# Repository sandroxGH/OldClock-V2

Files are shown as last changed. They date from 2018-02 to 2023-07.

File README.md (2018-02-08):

Old Clock V2.0
===================== 
Controller board for Odl train station clock 

Project preview
=====================
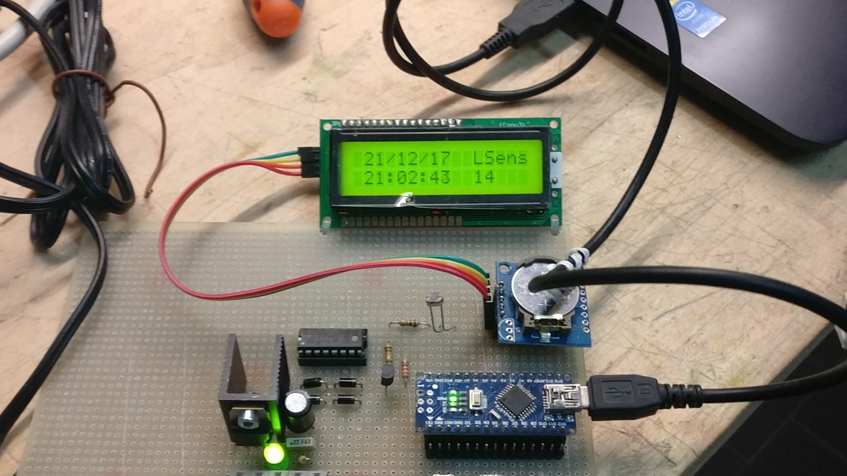
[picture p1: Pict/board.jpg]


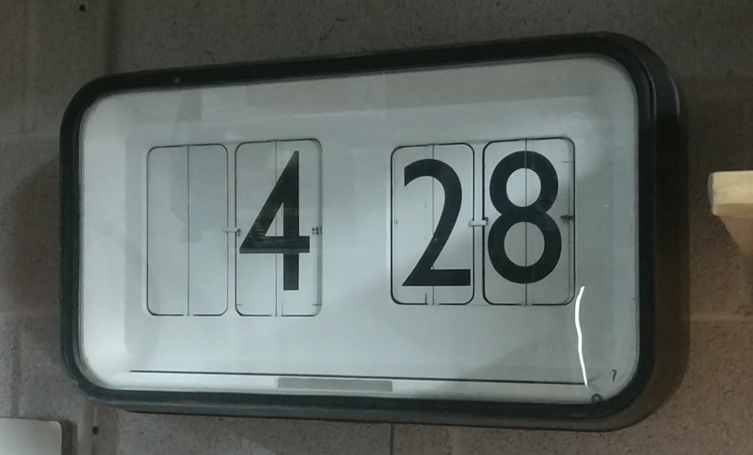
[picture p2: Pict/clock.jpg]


License and copyright
=====================

Copyright 2017-2018 sandroxGH infomsystemsrl@gmail.com

Licensed under the Apache License, Version 2.0 (the "License"); you may not use this file except in compliance with the License. You may obtain a copy of the License at http://www.apache.org/licenses/LICENSE-2.0

Unless required by applicable law or agreed to in writing, software distributed under the License is distributed on an "AS IS" BASIS, WITHOUT WARRANTIES OR CONDITIONS OF ANY KIND, either express or implied. See the License for the specific language governing permissions and limitations under the License.

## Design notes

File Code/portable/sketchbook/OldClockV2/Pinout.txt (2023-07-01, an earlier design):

1	D1/TX	SerialCon 
2	D0/RX	SerialCon
3	RESET
4	GND
5	D2*		Edit Button
6	D3		Up Button
7	D4		Down Button
8	D5*		Sensor for 0 meccanical detect
9	D6* 		Motor Direction 
10	D7		Motor Enable 
11	D8		Periphral Power 
12	D9* 		Green Led For Debug 
13	D10*		
14	D11* 		Led light 
15	D12  	
16	D13		Red Led program State 
17	3V3		
18	AREF
19	A7		
20	A6		
21	A5		
22	A4		
23	A3		
24	A2		
25	A1		Supply voltage control 
26	A0		Light Dependent Resistor
27	+5V
28	RESET
29	GND
30	VIN

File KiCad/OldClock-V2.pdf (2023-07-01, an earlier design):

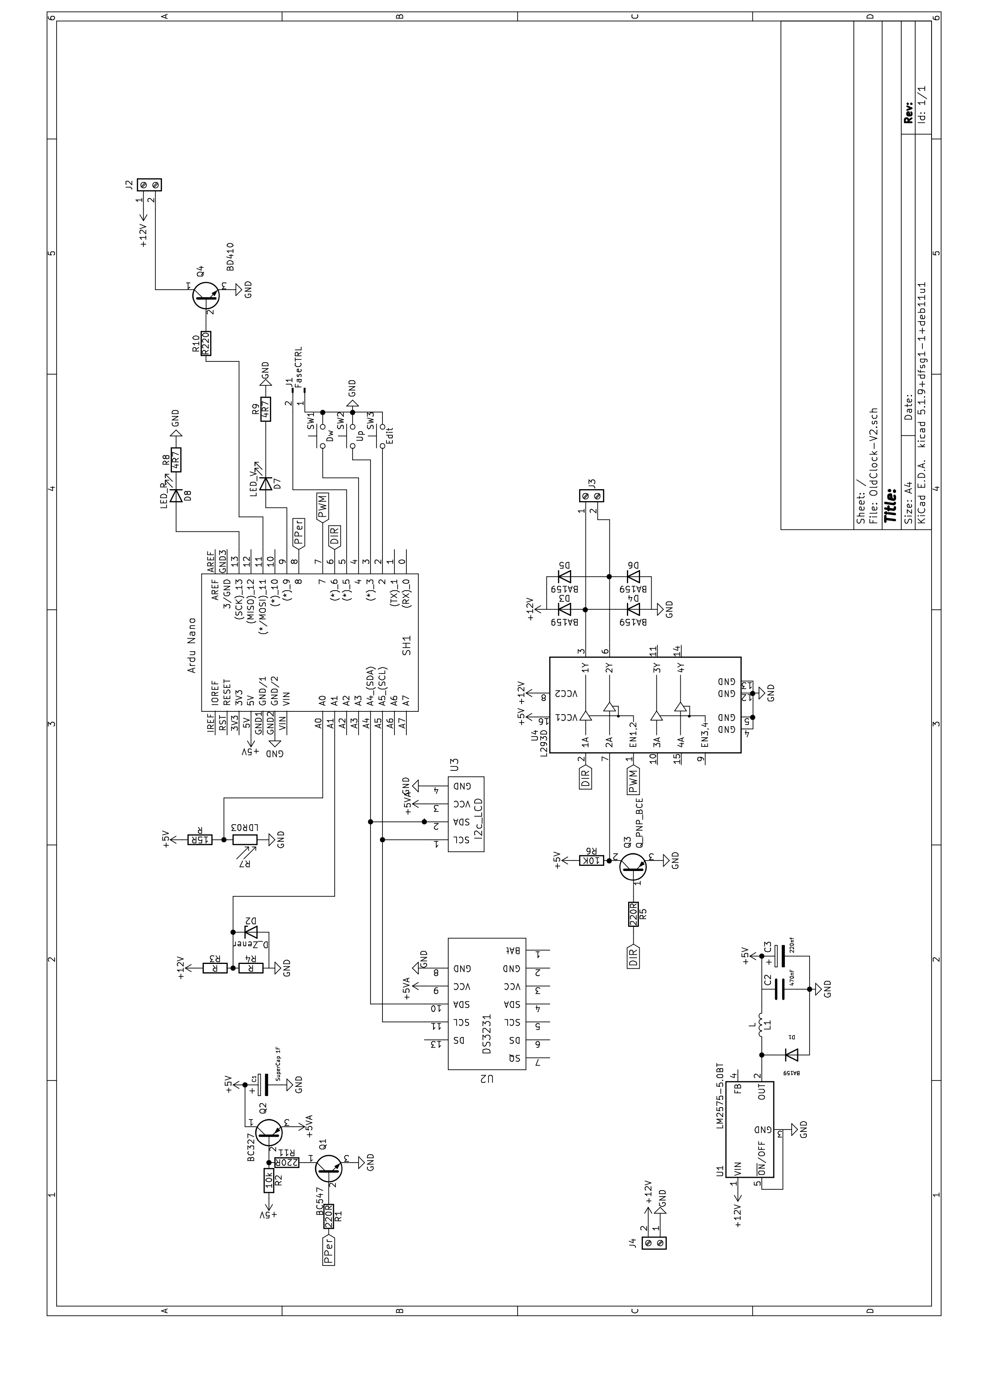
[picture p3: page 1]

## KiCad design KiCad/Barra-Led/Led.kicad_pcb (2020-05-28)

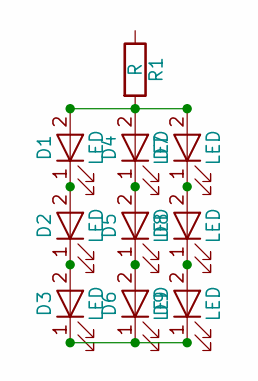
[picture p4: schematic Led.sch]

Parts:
D1, D2, D3, D4, D5, D6, D7, D8, D9: LED; 3528
R1: R; R_1210_HandSoldering

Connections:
unnamed: D1.1 (K), D2.2 (A)
unnamed: D1.2 (A), D4.2 (A), D7.2 (A), R1.2
unnamed: D2.1 (K), D3.2 (A)
unnamed: D3.1 (K), D6.1 (K), D9.1 (K)
unnamed: D4.1 (K), D5.2 (A)
unnamed: D5.1 (K), D6.2 (A)
unnamed: D7.1 (K), D8.2 (A)
unnamed: D8.1 (K), D9.2 (A)

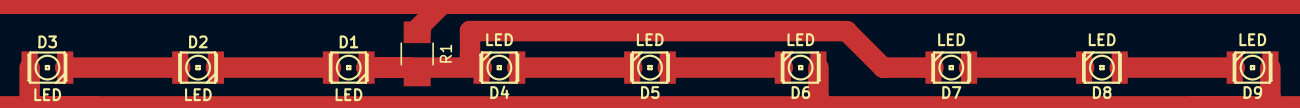
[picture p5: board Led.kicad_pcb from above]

Board: 2 copper layers, 10 parts (0 on the bottom side), 8 nets.

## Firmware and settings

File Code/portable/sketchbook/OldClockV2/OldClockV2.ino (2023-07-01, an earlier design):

/*
  Old clock for rail station V2.1
   This project is to control a flip clock using arduino nano with DS3231 RTC board,
   also a twilight control for night light.
   Can adjust: the date and time, motor speed for pallet revolution, twilight
   threshold, voltage supply allarm and event/alarm log history.
*/

#include <Wire.h>
#include <LCD.h>
#include <LiquidCrystal_I2C.h>
#include <EEPROM.h>
#include <avr/wdt.h>

//---------Alarm table-----------------
#define EVENT			'E'
#define ALARM			'A'
#define MESSAGE			'M'
#define START_UP		1
#define CHANGE_DATE		2
#define DATA_FAULT		3
#define MCL_WAITING		4
#define MCL_ADVANCE		5
#define MCL_DELAY		6
#define LCD_BUS_FAULT	7
#define RTC_BUSS_FAULT	8
#define EPR_BUSS_FAULT	9
#define RTC_NOT_RUN		10
#define SAVE_SHUTDOWN	11
#define SUMMER_TIME		12
#define STANDARD_TIME	13

//-------Alarm Led Blink Pattern-------
#define Pattern_No_All	2500
#define Pattern_All1    1000
#define Pattern_All2    500
#define Pattern_All3    200

//-----------Timer Setting-------------
#define EepromWipe		0 		// init procedure for new eeprom
#define EepromRead		0   	// all the eprom data is print on serial port in startup
#define SystemLog		1		// Enable of System Log on external eprom
#define FDebug			0		// Enable Fast Debug
#define SDebug			0		// Eneble Time Debug
#define TDebug			1000	// Time of debug 
#define TLcd			1000	// Time Lcd Refresh 
#define TTwl			2000	// Time for LDR value calculation
//#define TMotMan		61000	// Time 
#define TPatAll			30000	// Time of led alarm indication 
#define TExitMenu		30000	// Time for auto-exit menu 
#define TI2cTest		30000	// Time for bus test 
#define TSvTShDw		500		// Time to Save and Shutdown , power off the PerPwr enable

#define SelPatt			50		// Selection minimal time 
#define EntPatt			1500	// Enter
#define TPulButt		100		// Time for auto toogles button  

#define MenuPage		7		// Number of page in Menu 
#define SampleN			10		// Sample number for LDR Value 
#define TwlRDelta		30		// Delta between the Min and Max threshold in Twilight parameter 


#define UpLimMS			250		// Motor Speed limit
#define DwLimMS			12
#define UpLimTwlOn		250		// Twilight Sensor limit ON
#define DwLimTwlOn		10
#define	UpLimTwlOff		250		// Twilight Sensor limit OFF
#define DwLimTwlOff		10
#define UpLimVSens		140   // Limit for auto power off
#define DwLimVSens		50
#define HiEpromLim		4020	// Message limit for system log %10
#define LowEpromLim		0
#define EepromPageSize	32
#define SerAllMes		2



//---------LCD I2C Addres and pinout---
#define EEPROM_ADDR		0x57 ///0x50  simulator
#define LCD_I2C_ADDR	0x27 //0x20  simulator
#define DS3231_ADDR		0x68
//#define DS1307_ADDR	0x68
#define BACKLIGHT_PIN	3
#define En_pin			2
#define Rw_pin			1
#define Rs_pin			0
#define D4_pin			4
#define D5_pin			5
#define D6_pin			6
#define D7_pin			7


//----------Arduino PinOut-------------
#define EdButt		2
#define UpButt		3
#define DwButt		4  //5 simulator
#define FaseCTRL	5  //4 simulator
#define LDR			A0
#define VSens		A1  //Vin-Vout ratio 0.33
#define Light		11
#define LedV		9
#define LedR		13
#define MotDir		6
#define MotEn		7
#define PerPwr		8


//-----Arduino EEPROM data storage-----
#define M_MotSpeed		1
#define M_TwlR_On	  	2						//Twilight relays threshold On
#define M_TwlR_Off		3						//Twilight relays threshold Off
#define M_HMec			4
#define M_MMec			5
#define M_MDir			6
#define M_EpromAdd		7
#define M_EpromAdd1		8
#define M_VSensLim		9     // 12V Sensor limit under this limit save the parameter and disable motor movement 
#define M_SolarTime		10


unsigned long TimeLcd = 0;  		//Update LCD Time
unsigned long TimeDeb = 0;  		//Debug Time
unsigned long TimeTwl = 0;		//
unsigned long TimeMotMan = 0;		// Time to update the Mechanical time
unsigned long TimeMotEn = 0;
unsigned long TimeBlink = 0;
unsigned long TimeEdButt = 0;
unsigned long TimeUpButt	= 0;
unsigned long TimeDwButt = 0;
unsigned long TimePatt	= 0;
unsigned long TimeMenu 	= 0;
unsigned long TimeI2cTest = 0;
unsigned long TimeSvTShDw = 0;
unsigned long TimePulseUp	= 0;
unsigned long TimePulseDw  = 0;
unsigned long TMotMgmt =0;
unsigned long TMotEn =0;

byte DataTime[7];
byte SetDataTime[7];
byte AllBuff[10];
char buffer[30];
byte SerAll[3];
byte EpromPageOffset = 0;
byte NotAligLengt  = 0;

int EpromAdd;
unsigned int Pattern = 0;
int SetData, SetDataOld;
int HMec, MMec ;
int MotEnable;
int TwlR_On, TwlR_Off, TwlAve, TwlVal;
int VSensVal;
int VSensValOld;
int VSensLim;
int j,i;
int SumMinMec = 0;
int SumMinRtc = 0;
int MinOld =0;

char EditState = 0;
char Menu = 0;
char MenuOld = 0;
char Cursor, OldCursor;
char Sample;
char UpButtState, DwButtState;
char SerCount;
char SolarTime;
const char* DW[] = {"Lun", "Mar", "Mer","Gio", "Ven", "Sab", "Dom"}; //Day of week
const char* Adj[] = {"Leg","Sol","xxx"}; //Summer Standard time auto Adjust




byte Char10[8] = {
  B00010, B00100, B01000, B10000, B01011, B11011, B01011, B01011
};
byte CharV[8] = {
  B10001, B10001, B01010, B01010, B00100, B00001, B00010, B00100
};

bool AllReady  = 0;
bool MClAdAll  = 0;
bool MClDlAll  = 0;
bool MClWaAll	= 0;
bool LcdAll    = 0;
bool RtcAll    = 0;
bool EpromAll  = 0;
bool PattAllOn = 0;
bool MoveMot   = 0;
bool EditMode  = 0;
bool InitEdit  = 0;
bool SvTShDw  = 0;
bool PulseMem = 0;
bool LcdClear =0;

LiquidCrystal_I2C lcd(LCD_I2C_ADDR, En_pin, Rw_pin, Rs_pin, D4_pin, D5_pin, D6_pin, D7_pin);

void(* resetFunc) (void) = 0;   //Reset SW

void setup() {
  pinMode(EdButt, INPUT_PULLUP);
  pinMode(UpButt, INPUT_PULLUP);
  pinMode(DwButt, INPUT_PULLUP);
  pinMode(FaseCTRL, INPUT_PULLUP);
  pinMode(Light, OUTPUT);
  pinMode(LedR, OUTPUT);
  pinMode(LedV, OUTPUT);
  pinMode(MotDir, OUTPUT);
  pinMode(MotEn, OUTPUT);
  pinMode(PerPwr, OUTPUT);
  analogReference(DEFAULT);
  digitalWrite(PerPwr, HIGH);      //Turne On The Periferical Power
  delay(500);
  Wire.begin();
  lcd.begin(16, 2);
  lcd.createChar(6, CharV);
  lcd.createChar(7, Char10);
  Serial.begin(115200);
  Serial.println("OdlClockV2.2");
  lcd.setBacklightPin(BACKLIGHT_PIN, POSITIVE);
  lcd.setBacklight(HIGH);
  lcd.setCursor(4 , 0);
  lcd.print("Msystem");
  lcd.setCursor(1, 1);
  lcd.print("Old Clock V2.2");
  delay(1500);
  lcd.clear();
  lcd.setBacklight(LOW);
  MotEnable = EEPROM.read(M_MotSpeed);
  TwlR_On = EEPROM.read(M_TwlR_On);
  TwlR_Off = EEPROM.read(M_TwlR_Off);
  HMec = EEPROM.read(M_HMec);
  MMec = EEPROM.read(M_MMec);
  EpromAdd = EEPROM.read(M_EpromAdd1);
  EpromAdd = (EpromAdd << 8) + EEPROM.read(M_EpromAdd);
  EpromAdd += 10;
  digitalWrite(MotDir , EEPROM.read(M_MDir));
  VSensLim = EEPROM.read(M_VSensLim);
  SolarTime= EEPROM.read(M_SolarTime);

  // EpromAdd = 0;
  if (EpromAdd < LowEpromLim) EpromAdd = LowEpromLim;
  if (EepromWipe) {
    Serial.println("Erasing EEPROM");
    lcd.setCursor(1 , 0);
    lcd.print("Erasing EEPROM");
    for (j = 0; j < 10; j++) AllBuff[j] = 0;
    AllBuff[7] = '#';
    for (j = LowEpromLim; j <= HiEpromLim; j += 10)  EEpromWriteBuff(EEPROM_ADDR , j, &AllBuff[0], 10);
    EEPROM.write(M_EpromAdd, 0);
    EEPROM.write(M_EpromAdd1, 0);
    EpromAdd = LowEpromLim;
  }
  if (EepromRead) {
    Serial.println("EEPROM read Mesage");
    for (j = LowEpromLim; j <= HiEpromLim; j += 10) {
      EEpromReadBuff(EEPROM_ADDR , j, &AllBuff[0], 10);
      sprintf(buffer, "%02d;%02d/%02d/%02d;%02d:%02d:%02d;%c;%02d;%02d", ((j - LowEpromLim) / 10), AllBuff[2], AllBuff[1], AllBuff[0], AllBuff[4], AllBuff[5], AllBuff[6], AllBuff[7], AllBuff[8], AllBuff[9]);
      Serial.println(buffer);
    }
  }

  if (! GetDateTime(&DataTime[0])) {
    if (FDebug) Serial.println("RTC is NOT running!");
    Pattern = Pattern_All3;
    for (i = 0; i <= 6; i++) AllBuff[i] = 99;
    AllBuff[7] =  ALARM;
    AllBuff[8] = RTC_NOT_RUN;
    AllReady = 1;
  }
  else {
    for (i = 0; i <= 6; i++) AllBuff[i] = DataTime[i];
    AllBuff[7] = EVENT;
    AllBuff[8] = START_UP;
    AllReady = 1;
    Pattern = Pattern_No_All;
  }
  
   TimeMotMan = millis();
   TMotMgmt=5000;
 }

void Debug() {
  digitalWrite(LedV, !(digitalRead(LedV)));
  //  Serial.println("Debug Programma");
  //  Serial.print("Pattern");
  //  Serial.println(Pattern);
  //  Serial.print("VSens");
  //  Serial.println((analogRead(VSens) >> 2), DEC);
  //  Serial.print("MenuPg");
  //  Serial.println(Menu, DEC);
  //  Serial.print("Edit Mod");
  //  Serial.println(EditMode, DEC);
  //  Serial.print("InitEdit");
  //  Serial.println(InitEdit, DEC);
  //  Serial.print("Cursor");
  //  Serial.println(Cursor, DEC);
  //  Serial.print("HMec ");
  //  Serial.print(HMec, DEC);
  //  Serial.print("  ");
  //  Serial.println(DataTime[4], DEC);
  //  Serial.print("MMec ");
  //  Serial.print(MMec, DEC);
  //  Serial.print("  ");
  //  Serial.println(DataTime[5], DEC);
  //  Serial.print("Fase CTRL  ");
  //  Serial.println(digitalRead(FaseCTRL), DEC);
  //  Serial.print("SumMinMec");
  //  Serial.println(SumMinMec , DEC);
  //  Serial.print("SumMinRtc");
  //  Serial.println(SumMinRtc , DEC);
  //  Serial.print("VSensVal   ");
  //  Serial.println(VSensVal, DEC);
  //  Serial.print("VSensValOld   ");
  //  Serial.println(VSensValOld, DEC);
  //  Serial.println(analogRead(VSens));
  //  Serial.print("TimePulseUp ");
  //  Serial.println(TimePulseUp, DEC);
  //  Serial.print("TimeUpButt ");
  //  Serial.println(TimeUpButt, DEC);
  Serial.print("DataTime 3 ");
  Serial.println(DataTime[3], DEC);

}

char ButtonState(char PinN, unsigned long *Time, bool Pulse = 0 , unsigned long *Time1 = 0) {
  if ((*Time==0) && !digitalRead(PinN))  *Time = millis();
  if (Pulse && !digitalRead(PinN) && ((millis() -*Time) > (EntPatt * 3 )))  {
    if (*Time1 == 0 ) *Time1 = millis();
    if ((millis() - *Time1)>TPulButt) {
      *Time1 = millis();
      if (FDebug)Serial.print(F("3 "));
      return 1;
    }
  }
  if (Pulse && digitalRead(PinN)) *Time1 = 0;
  if (digitalRead(PinN) && (*Time)) {
    if ((millis() - *Time)> EntPatt) {
      *Time = 0;
      if (FDebug)Serial.println(F("2"));
      return 2;
    }
    if ((millis() - *Time)> SelPatt) {
      *Time = 0;
      if (FDebug)Serial.println(F("1"));
      return 1;
    }
    return 0;
  }  
  else return 0;
}

byte DecToBcd(byte val) {
  return (((val / 10) << 4) + (val % 10));
}

byte BcdToDec(byte val) {
  return (((val >> 4) * 10) + (val & 0b1111) );
}

boolean GetDateTime(uint8_t *Array) {
  Wire.beginTransmission(DS3231_ADDR);			// init the transmission starting from the address 0x00
  Wire.write(0x00);
  Wire.endTransmission();                // requires 7 bytes to the devicese with the address indicated the DS3231 uses 56 bits to record the date / time
  Wire.requestFrom(DS3231_ADDR, 7);
  if (Wire.available())
  {
    *(Array + 6) = BcdToDec(Wire.read());
    *(Array + 5) = BcdToDec(Wire.read());
    *(Array + 4) = BcdToDec(Wire.read() & 0b111111); 	// 24 hours mode I consider the first 6 bits
    *(Array + 3) = Wire.read(); 						// I do not need to convert (Range da 1 a 7 => 3 bit)
    *(Array + 2) = BcdToDec(Wire.read());
    *(Array + 1) = BcdToDec(Wire.read());
    *Array = BcdToDec(Wire.read());
    return true;
  }
  return false;
}

void SendDateTime(uint8_t *Array) {
  Wire.beginTransmission(DS3231_ADDR); 					// the first byte sent establishes the initial register on which to write
  Wire.write(0x00);
  for ( i = 7; i != 0; i--) {
    Wire.write(DecToBcd(*(Array + i - 1)));
  }
  Wire.write(0x00);
  Wire.endTransmission();
}

byte readByte() {
  while (!Serial.available()) delay(10);
  byte reading = 0;
  byte incomingByte = Serial.read();
  while (incomingByte != '\n')
  {
    if (incomingByte >= '0' && incomingByte <= '9')
      reading = reading * 10 + (incomingByte - '0');
    else;
    incomingByte = Serial.read();
  }
  Serial.flush();
  return reading;
}

boolean CtrlData(byte dd, byte mm, byte yy) {
  uint8_t GGMese[12] = {
    31, 28, 31, 30, 31, 30, 31, 31, 30, 31, 30, 31
  };
  if ((mm < 1) || (mm > 12)) return false;						 // Is not a mounth
  if (yy % 4 == 0) GGMese[1] = 29; 								 // leap year
  if (dd < 1 || dd > GGMese[mm - 1]) return false;
  return true;
}

void EEpromWriteBuff( int deviceaddress, int eeaddresspage, byte* buffer, int length ) {
  NotAligLengt = 0;
  EpromPageOffset = eeaddresspage % EepromPageSize;
  if (EpromPageOffset > 0)  {
    NotAligLengt = EepromPageSize - EpromPageOffset;
    if (length < NotAligLengt) NotAligLengt = length;
    EEpromWrite(deviceaddress , eeaddresspage , buffer, NotAligLengt);
    length -= NotAligLengt;
  }
  if (length > 0) {
    eeaddresspage += NotAligLengt;
    buffer += NotAligLengt;
    EEpromWrite(deviceaddress , eeaddresspage , buffer, length);
  }
}
void EEpromWrite( int deviceaddress, int eeaddresspage, byte*buffer, int length ) {
  byte c = 0;
  Wire.beginTransmission(deviceaddress);
  Wire.write(eeaddresspage >> 8); // MSB
  Wire.write(eeaddresspage & 0xFF); // LSB
  for ( c = 0; c < length ; c++) Wire.write(*(buffer + c));
  Wire.endTransmission();
  delay(10);
}

void EEpromReadBuff( int deviceaddress, int eeaddress, byte* buffer, int length ) {
  Wire.beginTransmission(deviceaddress);
  Wire.write(eeaddress >> 8); // MSB
  Wire.write(eeaddress & 0xFF); // LSB
  Wire.endTransmission();
  Wire.requestFrom(deviceaddress, length);
  int c = 0;
  for ( c = 0; c < length; c++ )
    if (Wire.available()) {
      (*(buffer + c)) = Wire.read();
    }
}


void loop() {

  //------------Time Debug Mng---------
  if (((millis()-TimeDeb)>TDebug)&& SDebug) {
    TimeDeb = millis();
    Debug();
   }
  
  //------------Alarm Log--------------
  if ((AllReady) && (SystemLog)) {
    EEpromWriteBuff(EEPROM_ADDR, EpromAdd , &AllBuff[0], 10);
    EEPROM.write(M_EpromAdd, EpromAdd);
    EEPROM.write(M_EpromAdd1, (EpromAdd >> 8));
    EpromAdd += 10;
    if (EpromAdd >= HiEpromLim) EpromAdd = LowEpromLim;
    if (EpromAdd < LowEpromLim) EpromAdd = LowEpromLim;
    AllReady = 0;
    AllBuff[7]= AllBuff[8]= AllBuff[9]=0;
   }

  //------------Shutdown & Restart-----
  if ((SvTShDw) && ((millis()-TimeSvTShDw)>TSvTShDw) && digitalRead(PerPwr)) {
    digitalWrite(PerPwr, LOW);
    if (FDebug) Serial.println("Per PWR Off");
    while (1) {
      VSensVal = ((analogRead(VSens) * 10) / 68);
      if (VSensVal > VSensLim + 20 && (VSensVal < 145))   resetFunc();
      delay(500);
      digitalWrite(LedR, !digitalRead(LedR));
    }
  }
  //------------
  //  if (Serial.available()) {
  //    SerAll[SerCount] = Serial.read();
  //    SerCount++;
  //    if ((SerCount >= SerAllMes)&&(!AllReady) {
  //      Serial.println("OK");
  //      sprintf(buffer, "%c;%02d;%02d" , SerAll[0], SerAll[1], SerAll[2]);
  //      Serial.println(buffer);
  //       SerCount=0;
  //       for (i = 0; i <= 6; i++) AllBuff[i] = DataTime[i];
  //        AllBuff[7] = SerAll[0];
  //        AllBuff[8] = SerAll[1];
  //        AllBuff[9] = SerAll[2];
  //        AllReady = 1;
  //        Pattern = Pattern_All1;
  //    }
  //  }

  //---------Red Led Program State-----

  if ((millis()-TimeBlink)>Pattern) {
    digitalWrite(LedR, (digitalRead(LedR ) ^ 1));
    if ((Pattern != Pattern_No_All) && !PattAllOn) {
      TimePatt=millis();
      PattAllOn = 1;
    }
    else TimeBlink = millis();
    if ((millis()-TimePatt)>TPatAll) {
      Pattern = Pattern_No_All;
      PattAllOn = 0;
    }
  }
  //------------I2c Bus Test-----------

  if (((millis()-TimeI2cTest)> TI2cTest) && (!AllReady)) {
    Wire.beginTransmission(LCD_I2C_ADDR);
    if (Wire.endTransmission()) {
      if (FDebug) Serial.println("Lcd Bus Fault");
      if (!LcdAll ) {
        for (i = 0; i <= 6; i++) AllBuff[i] = DataTime[i];
        AllBuff[7] = ALARM;
        AllBuff[8] = LCD_BUS_FAULT;
        AllReady = 1;
        Pattern = Pattern_All2;
        LcdAll = 1;
      }
      goto Out;
    }
    LcdAll = 0;
    Wire.beginTransmission(DS3231_ADDR);
    if (Wire.endTransmission()) {
      if (FDebug) Serial.println("RTC Bus Fault");
      if (!RtcAll ) {
        for (i = 0; i <= 6; i++) AllBuff[i] = DataTime[i];
        AllBuff[7] = ALARM;
        AllBuff[8] = RTC_BUSS_FAULT;
        AllReady = 1;
        Pattern = Pattern_All2;
        RtcAll = 1;
      }
      goto Out;
    }
    RtcAll = 0;
    Wire.beginTransmission(EEPROM_ADDR);
    if (Wire.endTransmission()) {
      if (FDebug) Serial.println("Eeprom Bus Fault");
      if (!EpromAll ) {
        for (i = 0; i <= 6; i++) AllBuff[i] = DataTime[i];
        AllBuff[7] = ALARM;
        AllBuff[8] = EPR_BUSS_FAULT;
        AllReady = 1;
        Pattern = Pattern_All2;
        EpromAll = 1;
      }
      goto Out;
    }
    EpromAll = 0;

Out:
    TimeI2cTest = millis();
  }
  //-------Supply Voltage Control------

  VSensVal = ((analogRead(VSens) * 10) / 68); //61);
  //VSensVal = 120;
  if ((VSensVal < VSensLim) && !SvTShDw) {
    EEPROM.write(M_MMec , MMec);
    EEPROM.write(M_HMec , HMec);
    EEPROM.write(M_MDir , digitalRead(MotDir));
    EEPROM.write(M_EpromAdd, EpromAdd);
    EEPROM.write(M_EpromAdd1, (EpromAdd >> 8));
    for (i = 0; i <= 6; i++) AllBuff[i] = DataTime[i];
    AllBuff[7] = ALARM;
    AllBuff[8] = SAVE_SHUTDOWN;
    AllReady = 1;
    Pattern = Pattern_All2;
    SvTShDw = 1;                        //Save To ShutDown
    TimeSvTShDw = millis();
    if (FDebug) Serial.println("Salvato");
   }
  //----------Summer/Standard Time adj-------
  if((DataTime[1]==3)&&(DataTime[2]>=25)&&(DataTime[3]==7)&&(DataTime[4]==2)&&(SolarTime!=2)){
    GetDateTime(&DataTime[0]);
    DataTime[4]+=1;
    SendDateTime(&DataTime[0]);
    SolarTime=0;
    EEPROM.write(M_SolarTime, 0);
    if (FDebug) Serial.println("Summer time");   // E12
    for (i = 0; i <= 6; i++) AllBuff[i] = DataTime[i];
    AllBuff[7] = EVENT;
    AllBuff[8] = SUMMER_TIME;
    AllReady = 1;
    Pattern = Pattern_All1;
   }

  if((DataTime[1]==10)&&(DataTime[2]>=25)&&(DataTime[3]==7)&&(DataTime[4]==3)&&(SolarTime!=1)&&(SolarTime!=2)){
    GetDateTime(&DataTime[0]);
    DataTime[4]-=1;
    SendDateTime(&DataTime[0]);
    SolarTime=1;
    EEPROM.write(M_SolarTime, 1);
    if (FDebug) Serial.println("Standard time");   // E13
    for (i = 0; i <= 6; i++) AllBuff[i] = DataTime[i];
    AllBuff[7] = EVENT;
    AllBuff[8] = STANDARD_TIME;
    AllReady = 1;
    Pattern = Pattern_All1;
   }

  //------------Motor Management-------
  if (Menu == 2 && InitEdit) goto EndMotMgmt;     // Jump to allow the mechanical time adjustment

  if (((millis()-TimeMotMan)>TMotMgmt) && !SvTShDw) {
    TimeMotMan = millis();
    TMotMgmt =  60500-(DataTime[6] * 1000);
    GetDateTime(&DataTime[0]);
    SumMinMec = (MMec + (HMec * 60));
    SumMinRtc = (DataTime[5] + (DataTime[4] * 60));

    if ((SumMinMec > SumMinRtc) && (SumMinMec < (SumMinRtc + 60))) {
      if (!MClWaAll) {
        if (FDebug) Serial.println("MCL_WAITING");   // E4
        for (i = 0; i <= 6; i++) AllBuff[i] = DataTime[i];
        AllBuff[7] = EVENT;
        AllBuff[8] = MCL_WAITING;
        AllReady = 1;
        Pattern = Pattern_All1;
        MClWaAll = 1;
      }
      goto EndMotMgmt;
    }

    if ((HMec <= 23) && (HMec > 2) && (MMec <= 59)  && digitalRead(FaseCTRL)) {
      if (FDebug) Serial.println("Attesa in Fase");
      HMec = DataTime[4];
      MMec = DataTime[5];
      if (!MClAdAll) {
        if (FDebug) Serial.println("MCL_ADVANCE");  //A5
        for (i = 0; i <= 6; i++) AllBuff[i] = DataTime[i];
        AllBuff[7] = ALARM;
        AllBuff[8] = MCL_ADVANCE;
        AllReady = 1;
        Pattern = Pattern_All1;
        MClAdAll = 1;
      }
      goto EndMotMgmt;
    }
    if (!HMec && !MMec && !digitalRead(FaseCTRL) && !MoveMot) {
      if (FDebug) Serial.println("Recupero Ritardo");
      MoveMot = 1;
      digitalWrite (MotEn , HIGH);
      TimeMotEn = millis();
      TimeMotMan = millis(); 
      TMotEn = (MotEnable* 15);
      TMotMgmt = (MotEnable * 40);
      if (!MClDlAll) {
        if (FDebug) Serial.println("MCL_DELAY");   //A6
        for (i = 0; i <= 6; i++) AllBuff[i] = DataTime[i];
        AllBuff[7] = ALARM;
        AllBuff[8] = MCL_DELAY;
        AllReady = 1;
        Pattern = Pattern_All1;
        MClDlAll = 1;
      }
      goto EndMotMgmt;
    }
    if (((HMec != DataTime[4]) || (MMec != DataTime[5])) && (MoveMot == 0)) {
      if (FDebug) Serial.println("Recupero");
      TimeMotEn = millis();
      TimeMotMan = millis();
      TMotEn= (MotEnable * 15); 
      TMotMgmt= (MotEnable * 40);   //20
      digitalWrite (MotEn , HIGH);
      MoveMot = 1;
      MClAdAll = MClDlAll = MClWaAll = 0;
    }
   }
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

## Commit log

2018-02-07 Updated schematics
    [OdlClock-V2.kicad_pcb, OdlClock-V2.sch]
2018-02-28 Modified Enable and Dir pin to avoid motor revolution during the USB reset Addere a restart procedure if the 12V go down for a small period
    [OldClockV2.ino]
2018-02-28 Modified SCH Enable and Dir pin to avoid motor revolution during the USB reset
    [OdlClock-V2.sch]
2018-02-28 Step Down regulator Q
    [OdlClock-V2.sch]
2018-02-28 Rename KiCad Project and pdf file
    [OldClock-V2.kicad_pcb, OldClock-V2.sch]
2018-03-01 New PCB for led light ba
    [Led.kicad_pcb, Led.sch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]
2018-03-03 Bug fix on Twilight On Off Setting, Modified autoreset procedure
    [OldClockV2.ino]
2018-03-04 Bug fix on Event Allrm Log A5 A6
    [OldClockV2.ino]
2020-05-28 Schematical update
    [Led.kicad_pcb, OldClock-V2.sch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]
2020-05-28 Millis overflow prevent
    Modified all the timer logic
    [OldClockV2.ino]
2020-06-01 Update for DS3231
    Schematical and library update
    New eeprom address.
    chmage pinout from simulator to final board
    [OldClock-V2.sch]
2023-07-01 KiCad file update
    [OldClock-V2.sch]
2023-07-01 Schematical and code update Schematical resistor valude in Vsens code to comment the Vsens Ratio
    [OldClock-V2.sch]
